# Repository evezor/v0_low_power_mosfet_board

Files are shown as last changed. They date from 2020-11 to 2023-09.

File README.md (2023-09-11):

# Low Power Mosfet Board
*please note this board has been deprecated.

An edge board containing 3 low power mosfets capable of powering small loads like relays, small fans and LEDs. Also 3 buttons.  Each output may be pulse width modulated.  Power can come from the bus or external sources, selectable by jumper.

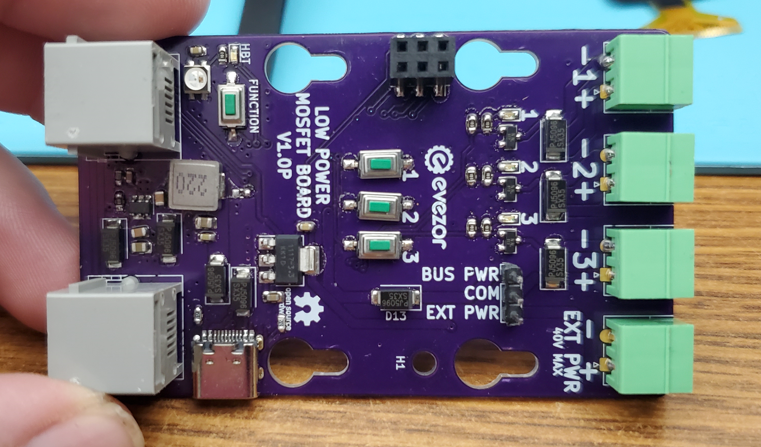
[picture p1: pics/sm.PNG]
sm


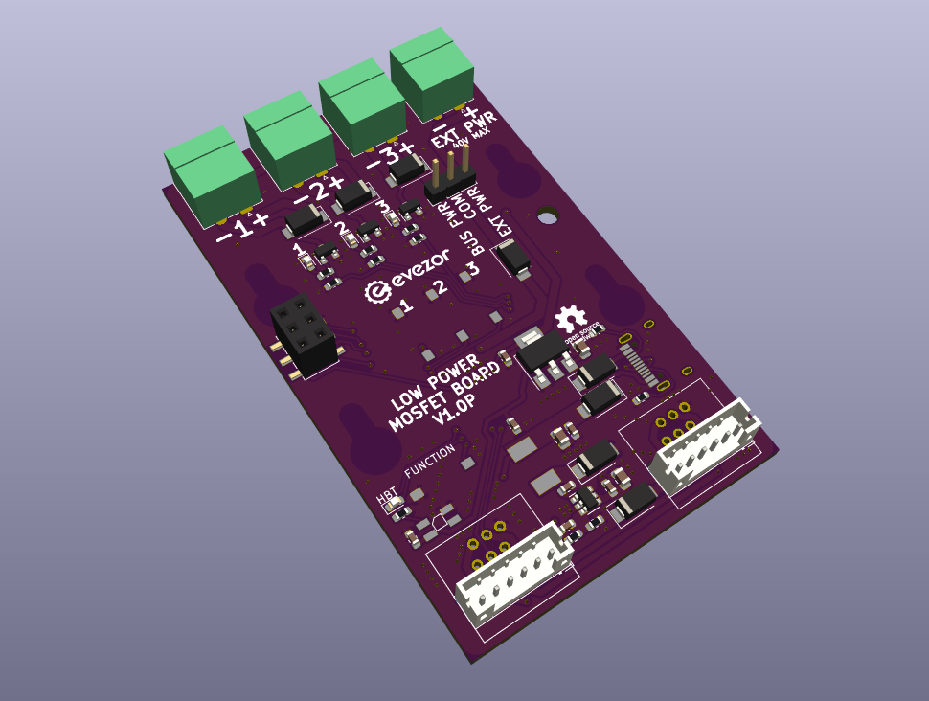
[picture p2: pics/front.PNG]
front


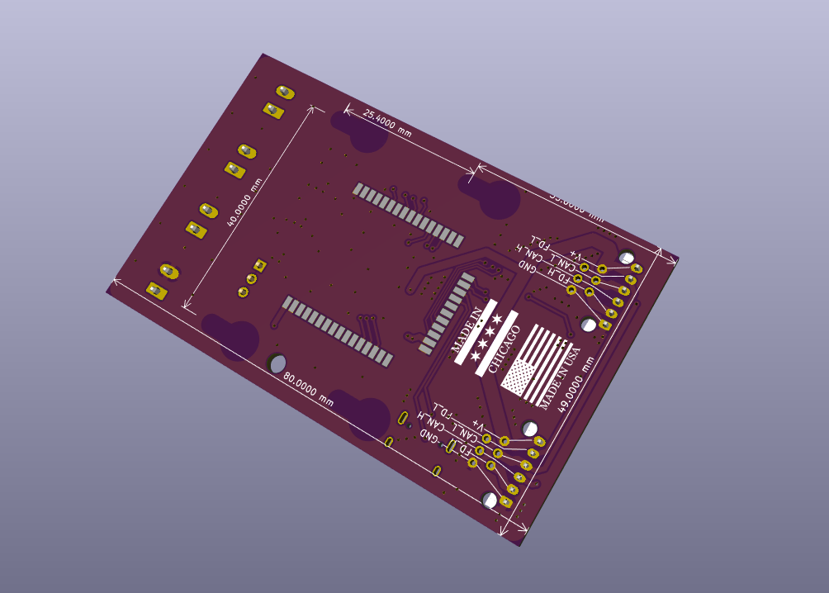
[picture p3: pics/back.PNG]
back


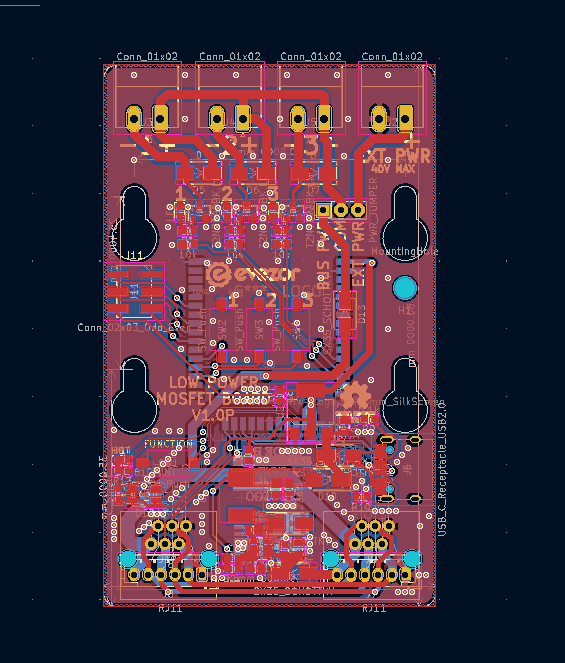
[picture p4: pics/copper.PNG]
copper


sch

source files can be found here: https://github.com/evezor/v0_low_power_mosfet_board

This board uses the Evezor Stamp STMF405 MCU

source: https://github.com/evezor/Evezor-Stamp-STMF405

Evezor® and all associated marks, logos, and designs are registered trademarks and protected by copyright. Unauthorized use or reproduction of these trademarks and copyrighted materials is strictly prohibited.

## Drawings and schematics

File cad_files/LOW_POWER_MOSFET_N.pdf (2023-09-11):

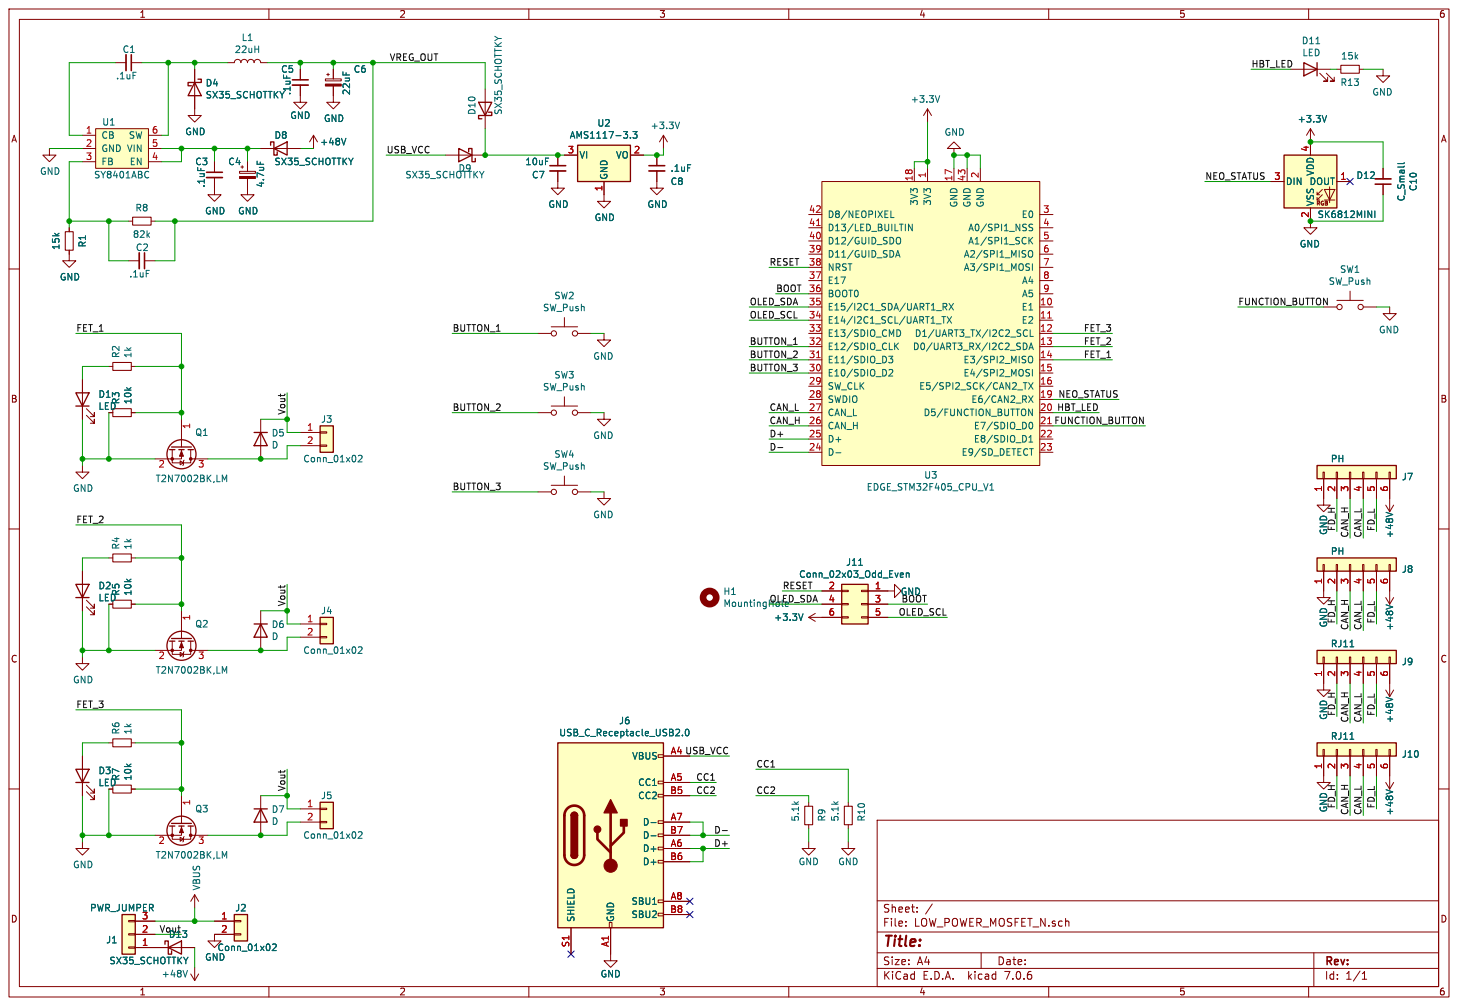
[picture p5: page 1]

2 D5/FUNCTION_BUTTON 20 E7/SDIO_D0 21 E8/SDIO_D1 22 E9/SD_DETECT 23 D- 24 D+ 25 CAN_H 26 CAN_L 27 SWDIO 28 SW_CLK 29 E0 3 E10/SDIO_D2 30 E11/SDIO_D3 31 E12/SDIO_CLK 32 E13/SDIO_CMD 33 E14/I2C1_SCL/UART1_TX 34 E15/I2C1_SDA/UART1_RX 35 BOOT0 36 E17 37 NRST 38 D11/GUID_SDA 39 A0/SPI1_NSS 4 D12/GUID_SDO 40 D13/LED_BUILTIN 41 D8/NEOPIXEL 42 GND 43 A1/SPI1_SCK 5 A2/SPI1_MISO 6 A3/SPI1_MOSI 7 A4 8 A5 9 U3 EDGE_STM32F405_CPU_V1 GND

Id: 1/1 Title: File: LOW_POWER_MOSFET_N.sch Sheet: / D13 SX35_SCHOTTKY
J1 PWR_JUMPER

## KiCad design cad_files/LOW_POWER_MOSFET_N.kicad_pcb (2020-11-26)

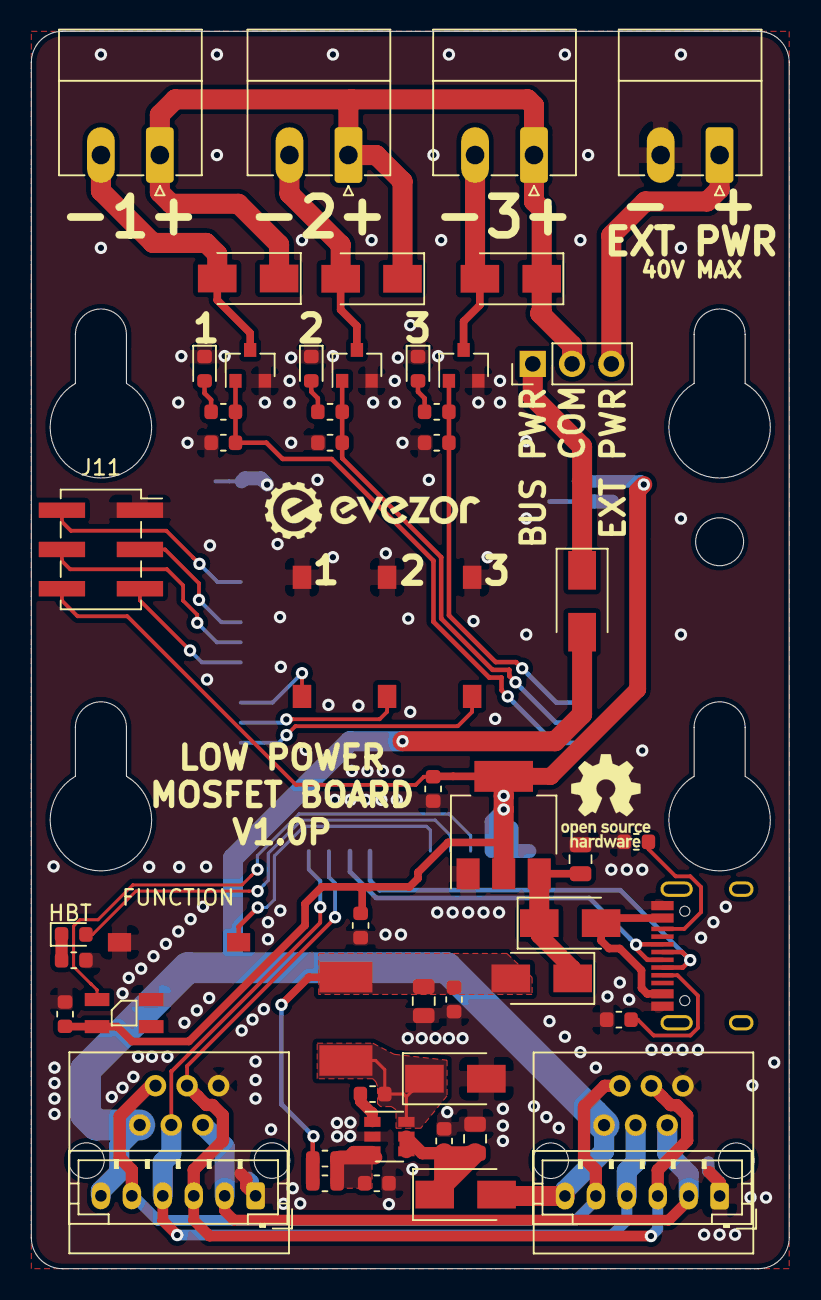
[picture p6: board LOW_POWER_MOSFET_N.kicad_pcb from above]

Board: 2 copper layers, 49.0 x 80.0 mm, 57 parts (1 on the bottom side), 41 nets.

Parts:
C1, C2, C3, C5, C8, C9: .1uF; C_0603_1608Metric
C4: 4.7uF; C_0805_2012Metric
C6: 22uF; C_0805_2012Metric
C7: 10uF; C_0805_2012Metric
C10: C_Small; C_0603_1608Metric
D1, D2, D3, D11: LED; LED_0603_1608Metric
D4, D8, D9, D10, D13: SX35_SCHOTTKY; D_SMA
D5, D6, D7: D; D_SMA
D12: SK6812MINI; LED_SK6812MINI_PLCC4_3.5x3.5mm_P1.75mm
H1: MountingHole; OLED_STANDOFF
J1: PWR_JUMPER; PinHeader_1x03_P2.54mm_Vertical
J2, J3, J4, J5: Conn_01x02; PhoenixContact_MC_1,5_2-G-3.81_1x02_P3.81mm_Horizontal
J6: USB_C_Receptacle_USB2.0; USB_C_Receptacle_HRO_TYPE-C-31-M-12
J7, J8: PH; JST_PH_B6B-PH-K_1x06_P2.00mm_Vertical
J9, J10: RJ11; RJ11_C189747_Horizontal
J11: Conn_02x03_Odd_Even; OLED_HEADER
L1: 22uH; INDUCTOR_7.5X6.6_GCDA0630-220MC
Q1, Q2, Q3: T2N7002BK,LM‎; SOT-23
R1, R13: 15k; R_0603_1608Metric
R2, R4, R6: 1k; R_0603_1608Metric
R3, R5, R7: 10k; R_0603_1608Metric
R8: 82k; R_0603_1608Metric
R9, R10: 5.1k; R_0603_1608Metric
SW1, SW2, SW3, SW4: SW_Push; SWITCH_2x3_SMD_TACTILE_GREEN
U1: SY8401ABC; SOT-23-6
U2: AMS1117-3.3; SOT-223-3_TabPin2
U3: EDGE_STM32F405_CPU_V1; EDGE_STAMP

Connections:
+3V3: C8.1, C9.1, C10.2, D12.4, J11.6, U2.2, U3.1, U3.18
+48V: D8.2, D13.2, J7.6, J8.6, J9.6, J10.6
/BOOT: J11.3, U3.36
/BUTTON_1: SW2.1, U3.32
/BUTTON_2: SW3.1, U3.31
/BUTTON_3: SW4.1, U3.30
/CAN_H: J7.3, J8.3, J9.3, J10.3, U3.26
/CAN_L: J7.4, J8.4, J9.4, J10.4, U3.27
/CC1: J6.A5, R10.1
/CC2: J6.B5, R9.1
/D+: J6.A6, J6.B6, U3.25
/D-: J6.A7, J6.B7, U3.24
/FD_H: J7.2, J8.2, J9.2, J10.2
/FD_L: J7.5, J8.5, J9.5, J10.5
/FET_1: Q1.1, R2.1, R3.2, U3.14
/FET_2: Q2.1, R4.1, R5.2, U3.13
/FET_3: Q3.1, R6.1, R7.2, U3.12
/FUNCTION_BUTTON: SW1.1, U3.21
/HBT_LED: D11.2, U3.20
/NEO_STATUS: D12.3, U3.19
/OLED_SCL: J11.5, U3.34
/OLED_SDA: J11.4, U3.35
/RESET: J11.2, U3.38
/USB_VCC: D9.2, J6.A4, J6.A9, J6.B4, J6.B9
/VREG_OUT: C2.1, C5.1, C6.1, D10.2, L1.2, R8.1
/Vout: D5.1, D6.1, D7.1, J1.2, J3.1, J4.1, J5.1
GND: C3.2, C4.2, C5.2, C6.2, C7.2, C8.2, C9.2, C10.1, D1.1, D2.1, D3.1, D4.2, D12.2, J2.2, J6.A1, J6.A12, J6.B1, J6.B12, J7.1, J8.1, J9.1, J10.1, J11.1, Q1.2, Q2.2, Q3.2, R1.1, R3.1, R5.1, R7.1, R9.2, R10.2, R13.1, SW1.2, SW2.2, SW3.2, SW4.2, U1.2, U2.1, U3.2, U3.17, U3.43
unnamed: C1.1, D4.1, L1.1, U1.6
unnamed: C1.2, U1.1
unnamed: C2.2, R1.2, R8.2, U1.3
unnamed: C3.1, C4.1, D8.1, U1.4, U1.5
unnamed: C7.1, D9.1, D10.1, U2.3
unnamed: D1.2, R2.2
unnamed: D2.2, R4.2
unnamed: D3.2, R6.2
unnamed: D5.2, J3.2, Q1.3
unnamed: D6.2, J4.2, Q2.3
unnamed: D7.2, J5.2, Q3.3
unnamed: D11.1, R13.2
unnamed: D13.1, J1.1
VBUS: J1.3, J2.1

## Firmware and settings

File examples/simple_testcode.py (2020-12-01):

#Low Power Mosfet v1.0p test code

from machine import Pin
from pyb import CAN, Timer
import utime


print("starting Low Power Mosfet test")
print("v1.0")
print("initializing")
can = CAN(1, CAN.NORMAL)
can.setfilter(0, CAN.LIST16, 0, (123, 124, 125, 126))


#Setup Pins
HBT_LED = Pin("D5", Pin.OUT)
FUNC_BUTTON = Pin("E7", Pin.IN, Pin.PULL_UP) 
NEO_STATUS = Pin("E6", Pin.OUT)
can_wakeup = Pin("D6", Pin.OUT)
can_wakeup.value(0)

BUTTON_1 = Pin("E12", Pin.IN, Pin.PULL_UP) 
BUTTON_2 = Pin("E11", Pin.IN, Pin.PULL_UP) 
BUTTON_3 = Pin("E10", Pin.IN, Pin.PULL_UP) 

FET_1 = Pin("E3", Pin.OUT) #Timer 12, Chan 1 
FET_2 = Pin("D0", Pin.OUT) #Timer 2, Chan 4   
FET_3 = Pin("D1", Pin.OUT) #Timer 2, Chan 3
    
TIMER_12 = Timer(12, freq=1000) 
TIMER_2 = Timer(2, freq=1000)

FET_1_DUTY = TIMER_12.channel(1, Timer.PWM, pin=FET_1)
FET_2_DUTY = TIMER_2.channel(4, Timer.PWM, pin=FET_2)
FET_3_DUTY = TIMER_2.channel(3, Timer.PWM, pin=FET_3)

    
    
    
    #Setup hbt timer
hbt_state = 0
hbt_interval = 500
start = utime.ticks_ms()
next_hbt = utime.ticks_add(start, hbt_interval)
HBT_LED.value(hbt_state)


print("starting")


def chk_hbt():
    global next_hbt
    global hbt_state
    now = utime.ticks_ms()
    if utime.ticks_diff(next_hbt, now) <= 0:
        if hbt_state == 1:
            hbt_state = 0
            HBT_LED.value(hbt_state)
            #print("hbt")
        else:
            hbt_state = 1
            HBT_LED.value(hbt_state)  
        
        next_hbt = utime.ticks_add(next_hbt, hbt_interval)

      

def send():
    can.send('lowPrFET', 123)   # send a message with id 123
    
def get():
    mess = can.recv(0)
    print(mess)
    simple_test()

def simple_test():
    print("starting test")
    for i in range(50):
        FET_1_DUTY.pulse_width_percent(i*2)
        utime.sleep_ms(10)
    for i in range(50):
        FET_1_DUTY.pulse_width_percent(100-(i*2))
        utime.sleep_ms(10)
    FET_1_DUTY.pulse_width_percent(0)
    for i in range(50):
        FET_2_DUTY.pulse_width_percent(i*2)
        utime.sleep_ms(10)
    for i in range(50):
        FET_2_DUTY.pulse_width_percent(100-(i*2))
        utime.sleep_ms(10)
    FET_2_DUTY.pulse_width_percent(0)
    for i in range(50):
        FET_3_DUTY.pulse_width_percent(i*2)
        utime.sleep_ms(10)
    for i in range(50):
        FET_3_DUTY.pulse_width_percent(100-(i*2))
        utime.sleep_ms(10)
    FET_3_DUTY.pulse_width_percent(0)

while True:
    chk_hbt()
    if not (FUNC_BUTTON.value()):
        print("function button")
        send()
        simple_test()
        utime.sleep_ms(200)
    
    if(can.any(0)):
        get()
    
    if not (BUTTON_1.value()):
        print("BUTTON_1 button")
        for i in range(50):
            FET_1_DUTY.pulse_width_percent(i*2)
            utime.sleep_ms(15)
        for i in range(50):
            FET_1_DUTY.pulse_width_percent(100-(i*2))
            utime.sleep_ms(15)
        FET_1_DUTY.pulse_width_percent(0)
    if not (BUTTON_2.value()):
        print("BUTTON_2 button")
        for i in range(50):
            FET_2_DUTY.pulse_width_percent(i*2)
            utime.sleep_ms(15)
        for i in range(50):
            FET_2_DUTY.pulse_width_percent(100-(i*2))
            utime.sleep_ms(15)
        FET_2_DUTY.pulse_width_percent(0)
    if not (BUTTON_3.value()):
        print("BUTTON_3 button")
        for i in range(50):
            FET_3_DUTY.pulse_width_percent(i*2)
            utime.sleep_ms(15)
        for i in range(50):
            FET_3_DUTY.pulse_width_percent(100-(i*2))
            utime.sleep_ms(15)
        FET_3_DUTY.pulse_width_percent(0)
        
        

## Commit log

2020-11-26 Add testcode and remove unneded silkscreen
    [LOW_POWER_MOSFET_N.kicad_pcb]
2023-09-11 add schematics
